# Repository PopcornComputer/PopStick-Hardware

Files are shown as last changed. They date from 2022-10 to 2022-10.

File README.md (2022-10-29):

# PopStick™ Hardware
[][cc-by-nc-sa]
[][twitter-follow]
[][sourceparts-subreddit]
<p align="center">PopStick USB Computer Device</p>

## Purchase
**PopStick™** is available for purchase in our webstore: [https://shop.popcorncomputer.com/products/popstick][webstore]

## Learn More
For a general overview, please visit the PopStick™ USB Computer website: [https://usbcomputer.com][usbcomputer]<br>
To learn how to use **PopStick™** or learn in more detail about how it works, please make sure to check out the link to the documentation below.

## Documentation
To view the documentation for **PopStick™** please visit: [https://docs.usbcomputer.com][usbcomputer-docs]

If you have done something cool with **PopStick™** or feel that something is missing from the documentation, please feel free to open an issue in the [documentation repository][documentation-repo] or submit a Pull Request in that repository. The source files for our documentation website can be found in the /docs folder in the [documentation repository][documentation-repo].

## License & Copyright
This work is licensed under a
[Creative Commons Attribution-NonCommercial-ShareAlike 4.0 International License][cc-by-nc-sa].

[][cc-by-nc-sa]

Source Parts Inc. © 2022

**PopStick™** is a trademark of Source Parts Inc.

[cc-by-nc-sa]: http://creativecommons.org/licenses/by-nc-sa/4.0/
[cc-by-nc-sa-image]: https://licensebuttons.net/l/by-nc-sa/4.0/88x31.png
[cc-by-nc-sa-shield]: https://img.shields.io/badge/License-CC%20BY--NC--SA%204.0-lightgrey.svg
[twitter-follow]: https://twitter.com/intent/follow?screen_name=sourceparts
[twitter-follow-shield]: https://img.shields.io/twitter/follow/sourceparts?style=social&logo=twitter
[sourceparts-subreddit]: https://reddit.com/r/sourceparts
[reddit-subscribers-shield]: https://img.shields.io/reddit/subreddit-subscribers/sourceparts?style=social
[usbcomputer]: https://usbcomputer.com
[usbcomputer-docs]: https://docs.usbcomputer.com
[webstore]: https://shop.popcorncomputer.com/products/popstick
[documentation-repo]: https://github.com/PopcornComputer/PopStick

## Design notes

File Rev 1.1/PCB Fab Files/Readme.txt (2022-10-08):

Board name	: Popcorn Popstick
Rev		: 1.1

Board Technology information:

No. of Layers		- FOUR(4)

Board Size 		- 45mm x 19mm

Track/Spacing		- 6mil track and 6mil spacing.

Via			- 24mil pad and 12mil drill
               
Component		- Mixed Technology

Gerber Format		- RS274-X

=================================================================

Note :

Please refer DRILL.art for stackup details.

Please confirm IPC netlist verification.

=================================================================

List of files in GERBER / arttoplotting

TOP.art		-> Gerber, Top side artwork
GND.art		-> Gerber, Inner layer2 artwork
VCC.art		-> Gerber, Inner layer3 artwork
BOT.art		-> Gerber, Bot side artwork
SMT.art		-> Gerber, Top side Solder Mask
SMB.art		-> Gerber, Bot side Solder Mask
SST.art		-> Gerber, Top side Silkscreen
SSB.art		-> Gerber, Bot side Silkscreen

List of files in DRILL/ NC Drill

nc_tools_auto.txt	-> NC drill tool bit information
Popcorn Popstick_Rev1p1-1-4.drl	-> NC Drill file in excellon format
FAB.art			-> Gerber, Drill drawing

=================================================================

Popcorn Popstick_Rev1p1_Release.pdf -> File for visual compliance

Popcorn Popstick_Rev1p1_Release.IPC -> IPC-D-356 netlist

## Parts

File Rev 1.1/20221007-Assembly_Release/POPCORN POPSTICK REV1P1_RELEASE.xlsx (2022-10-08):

CC BY-SA 4.0 Revision: 1.1
Bill Of Materials June 30,2022 17:55:15 | Page1
Item | Quantity | Reference | Part | PCB Footprint
1 | 1 | C2 | 10uF | 0603
2 | 3 | C5,C6,C7 | 2u2 | 0603
3 | 12 | C3,C8,C9,C10,C11,C13,C17,C26,C27,C28,C29,C30 | 100nF | 0603
4 | 3 | C14,C15,C16 | 22uF | 0603
5 | 2 | C20,C23 | 1uF | 0603
6 | 2 | C24,C25 | 20pF | 0603
7 | 2 | D1,D2 | MBR0540WS | SOD-323
8 | 2 | D3,D4 | LED | 0603
9 | 1 | F1 | 0467001.NRHF | 0603
10 | 3 | L1,L2,L3 | 2u2/CMP201209UD2R2MT | 0805
11 | 3 | Q1,Q2,Q3 | MMBT3904 | SOT23-3
12 | 3 | R1,R2,R15 | 11K | 0603
13 | 3 | R3,R16,R17 | 10K | 0603
14 | 3 | R4,R10,R11 | 49K9 | 0603
15 | 1 | R21 | DNP | 0603
16 | 1 | R5 | 36K | 0603
17 | 1 | R6 | 8K2 | 0603
18 | 2 | R7 | 330R | 0603
19 | 2 | R8,R9 | 2K2 | 0603
20 | 4 | R12,R13,R14,R20 | 1K | 0603
21 | 1 | R18 | 22R | 0603
22 | 1 | R19 | 0R | 0603
23 | 2 | SW1,SW2 | KEY-2PIN_0 | SW_4P_TC3061B
24 | 1 | SW3 | SW KEY_SPDT | K3-1296S-E1
25 | 1 | U1 | F1C200s | QFN88
26 | 1 | U2 | CH340E | MSOP10
27 | 1 | U3 | W25N01GVZEIG | WSON
28 | 3 | U4,U5,U6 | JW5211 | SOT23-5
29 | 1 | XTAL1 | 24M-20pF-10PPM | CRYSTAL-4P-3225-H1A
30 | 1 | X1 | USB | USB
31 | 1 | X2 | DNP | QWIIC_CONN
32 | 1 | X3 | USB-MICROB-SOCKET | USB-MICROB-SOCKET
33 | 1 | X4 | SOFNG-TF-015 | SOFNG-TF-015
34 | 1 | X5 | DNP | soic_bite

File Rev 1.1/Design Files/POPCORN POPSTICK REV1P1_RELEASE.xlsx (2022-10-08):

POPSTICK Revised: Thursday, June 30, 2022
CC BY-SA 4.0 Revision: 1.1
Bill Of Materials June 30,2022 17:55:15 | Page1
Item | Quantity | Reference | Part | PCB Footprint
______________________________________________
1 | 1 | C2 | 10uF | 603
2 | 4 | C3,C28,C29,C30 | 0.1uF | 603
3 | 3 | C5,C6,C7 | 2u2 | 603
4 | 8 | C8,C9,C10,C11,C13,C17,C26,C27 | 100nF | 603
5 | 3 | C14,C15,C16 | 22uF | 603
6 | 2 | C20,C23 | 1uF | 603
7 | 2 | C24,C25 | 20pF | 603
8 | 2 | D1,D2 | MBR0540WS | SOD-323
9 | 2 | D3,D4 | LED | 603
10 | 1 | F1 | 0467001.NRHF | 603
11 | 3 | L1,L2,L3 | 2u2/CMP201209UD2R2MT | 805
12 | 3 | Q1,Q2,Q3 | MMBT3904 | SOT23-3
13 | 3 | R1,R2,R15 | 11K | 603
14 | 3 | R3,R16,R17 | 10K | 603
15 | 5 | R4,R10,R11,R20,R21 | 49K9 | 603
16 | 1 | R5 | 36K | 603
17 | 1 | R6 | 8K2 | 603
18 | 2 | R7,R19 | 330R | 603
19 | 2 | R8,R9 | 2K2 | 603
20 | 3 | R12,R13,R14 | 1K | 603
21 | 1 | R18 | 22R | 603
22 | 2 | SW1,SW2 | KEY-2PIN_0 | SW_4P_TC3061B
23 | 1 | SW3 | SW KEY_SPDT | K3-1296S-E1
24 | 1 | U1 | F1C200s | QFN88
25 | 1 | U2 | CH340E | msop10
26 | 1 | U3 | W25N01GVZEIG | WSON
27 | 3 | U4,U5,U6 | JW5211 | SOT23-5
28 | 1 | XTAL1 | 24M-20pF-10PPM | CRYSTAL-4P-3225-H1A
29 | 1 | X1 | USB | USB
30 | 1 | X2 | DNP | QWIIC_CONN
31 | 1 | X3 | USB-MICROB-SOCKET | usb-mic-a01sb141bh2_4a
32 | 1 | X4 | SOFNG-TF-015 | SOFNG-TF-015
33 | 1 | X5 | SOIC BITE | soic_bite

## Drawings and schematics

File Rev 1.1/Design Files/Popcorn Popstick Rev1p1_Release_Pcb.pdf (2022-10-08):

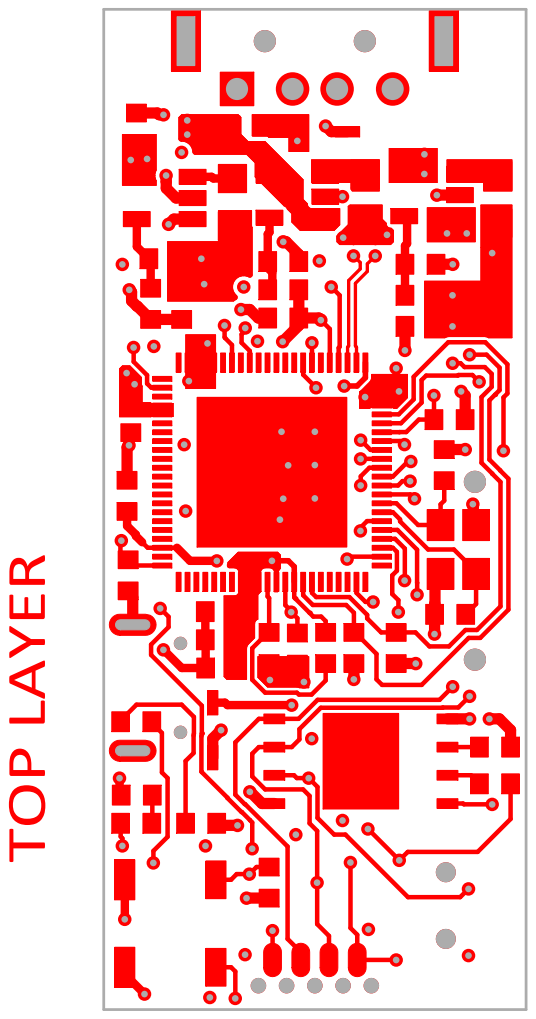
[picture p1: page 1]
TOP LAYER

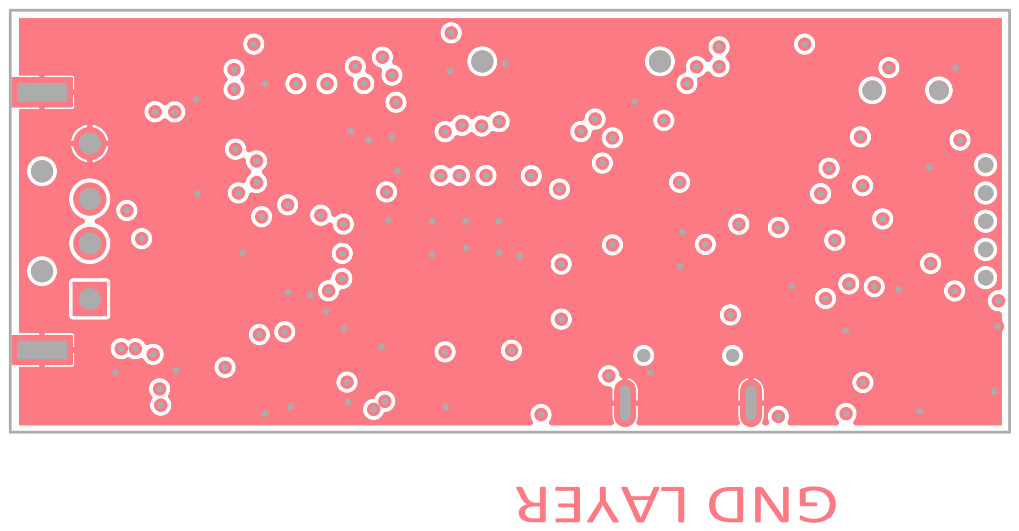
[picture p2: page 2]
GND LAYER

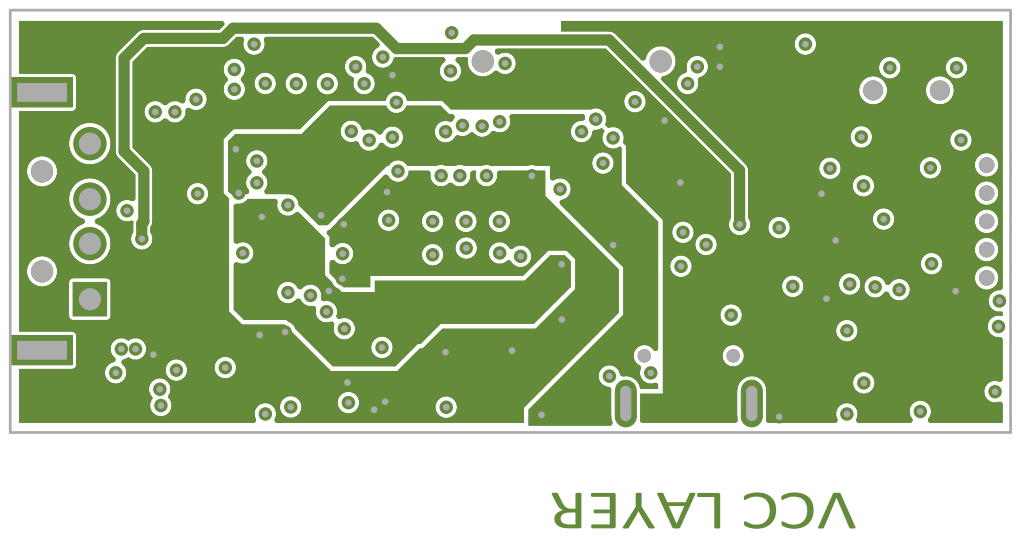
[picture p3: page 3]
VCC LAYER

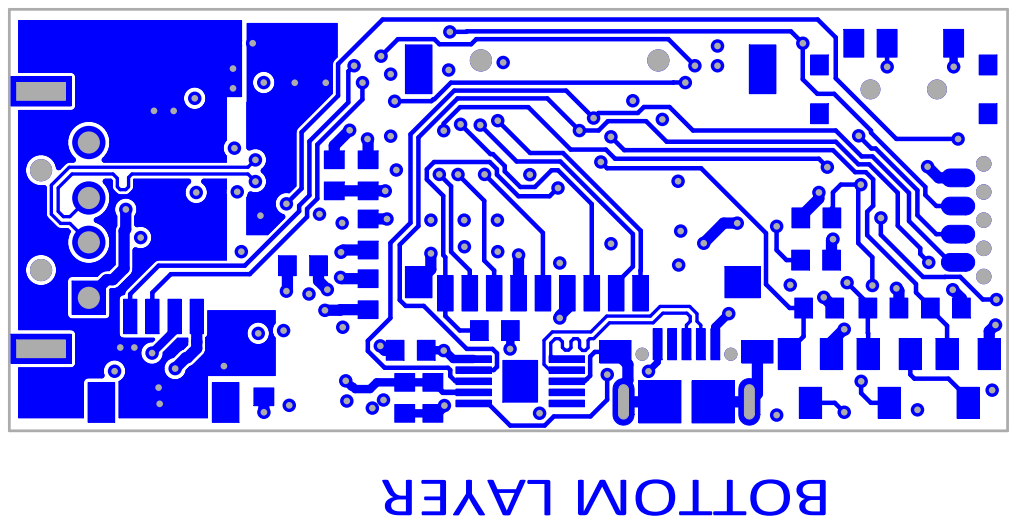
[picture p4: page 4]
BOTTOM LAYER

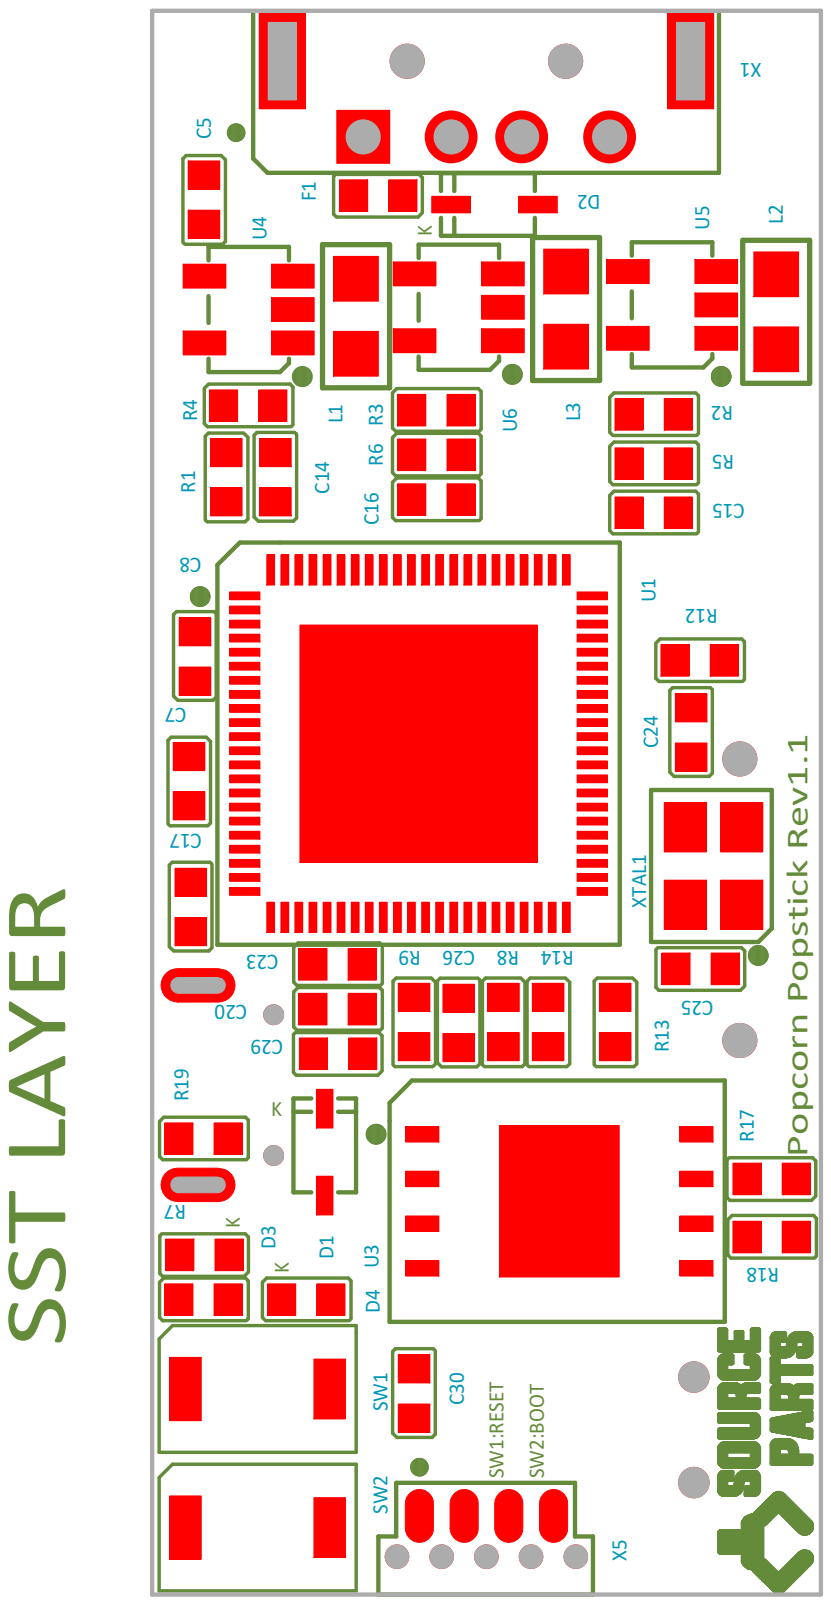
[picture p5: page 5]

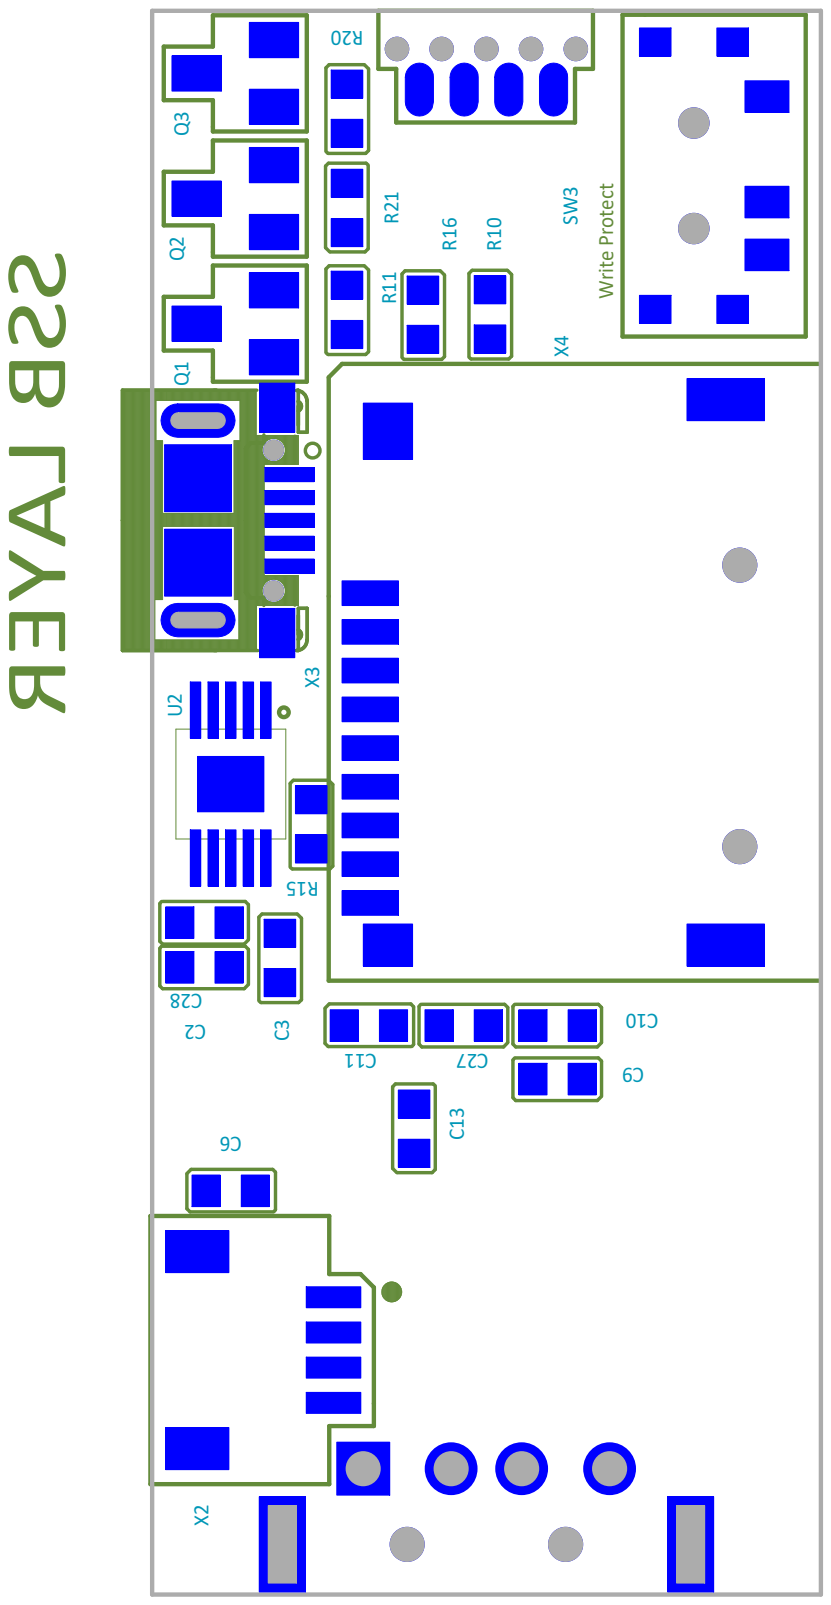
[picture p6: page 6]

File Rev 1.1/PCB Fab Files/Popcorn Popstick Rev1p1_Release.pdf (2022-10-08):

TOP LAYER

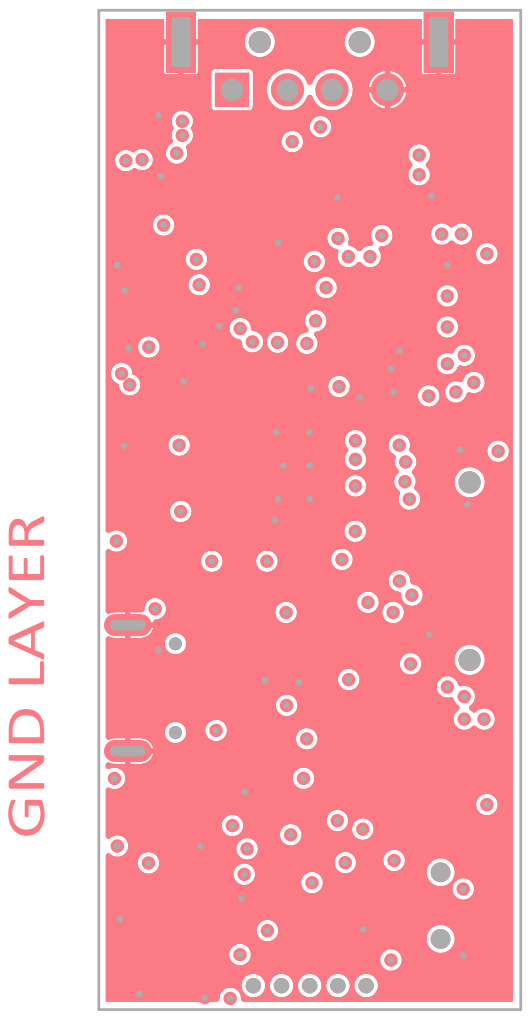
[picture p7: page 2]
GND LAYER

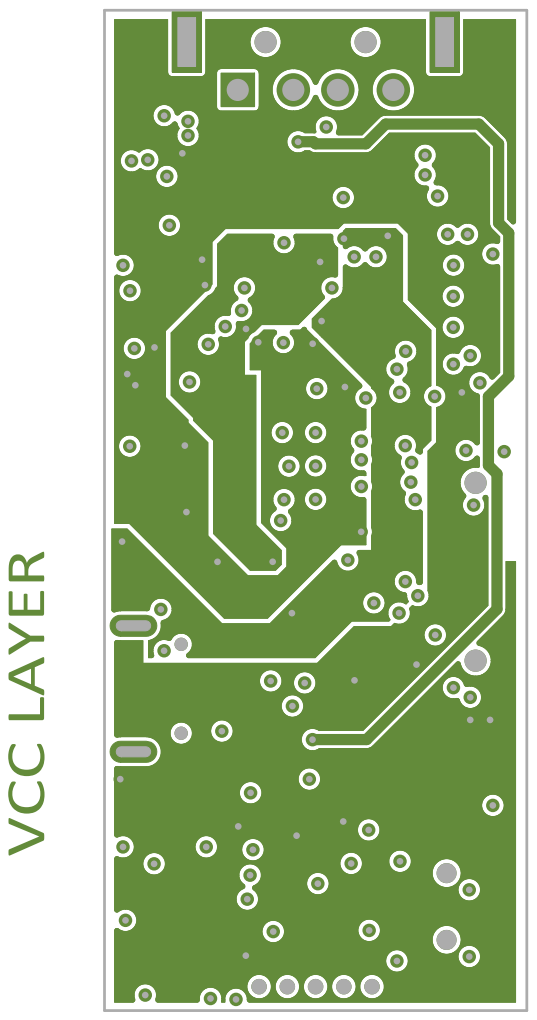
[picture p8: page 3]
VCC LAYER

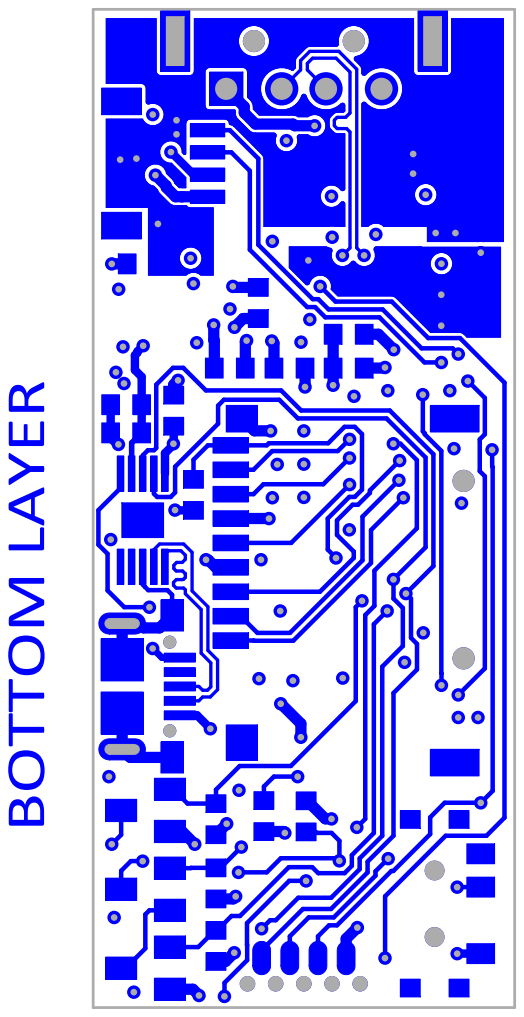
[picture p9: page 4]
BOTTOM LAYER



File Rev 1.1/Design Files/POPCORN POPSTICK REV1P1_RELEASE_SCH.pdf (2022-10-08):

# SD CARD QWIIC CONN

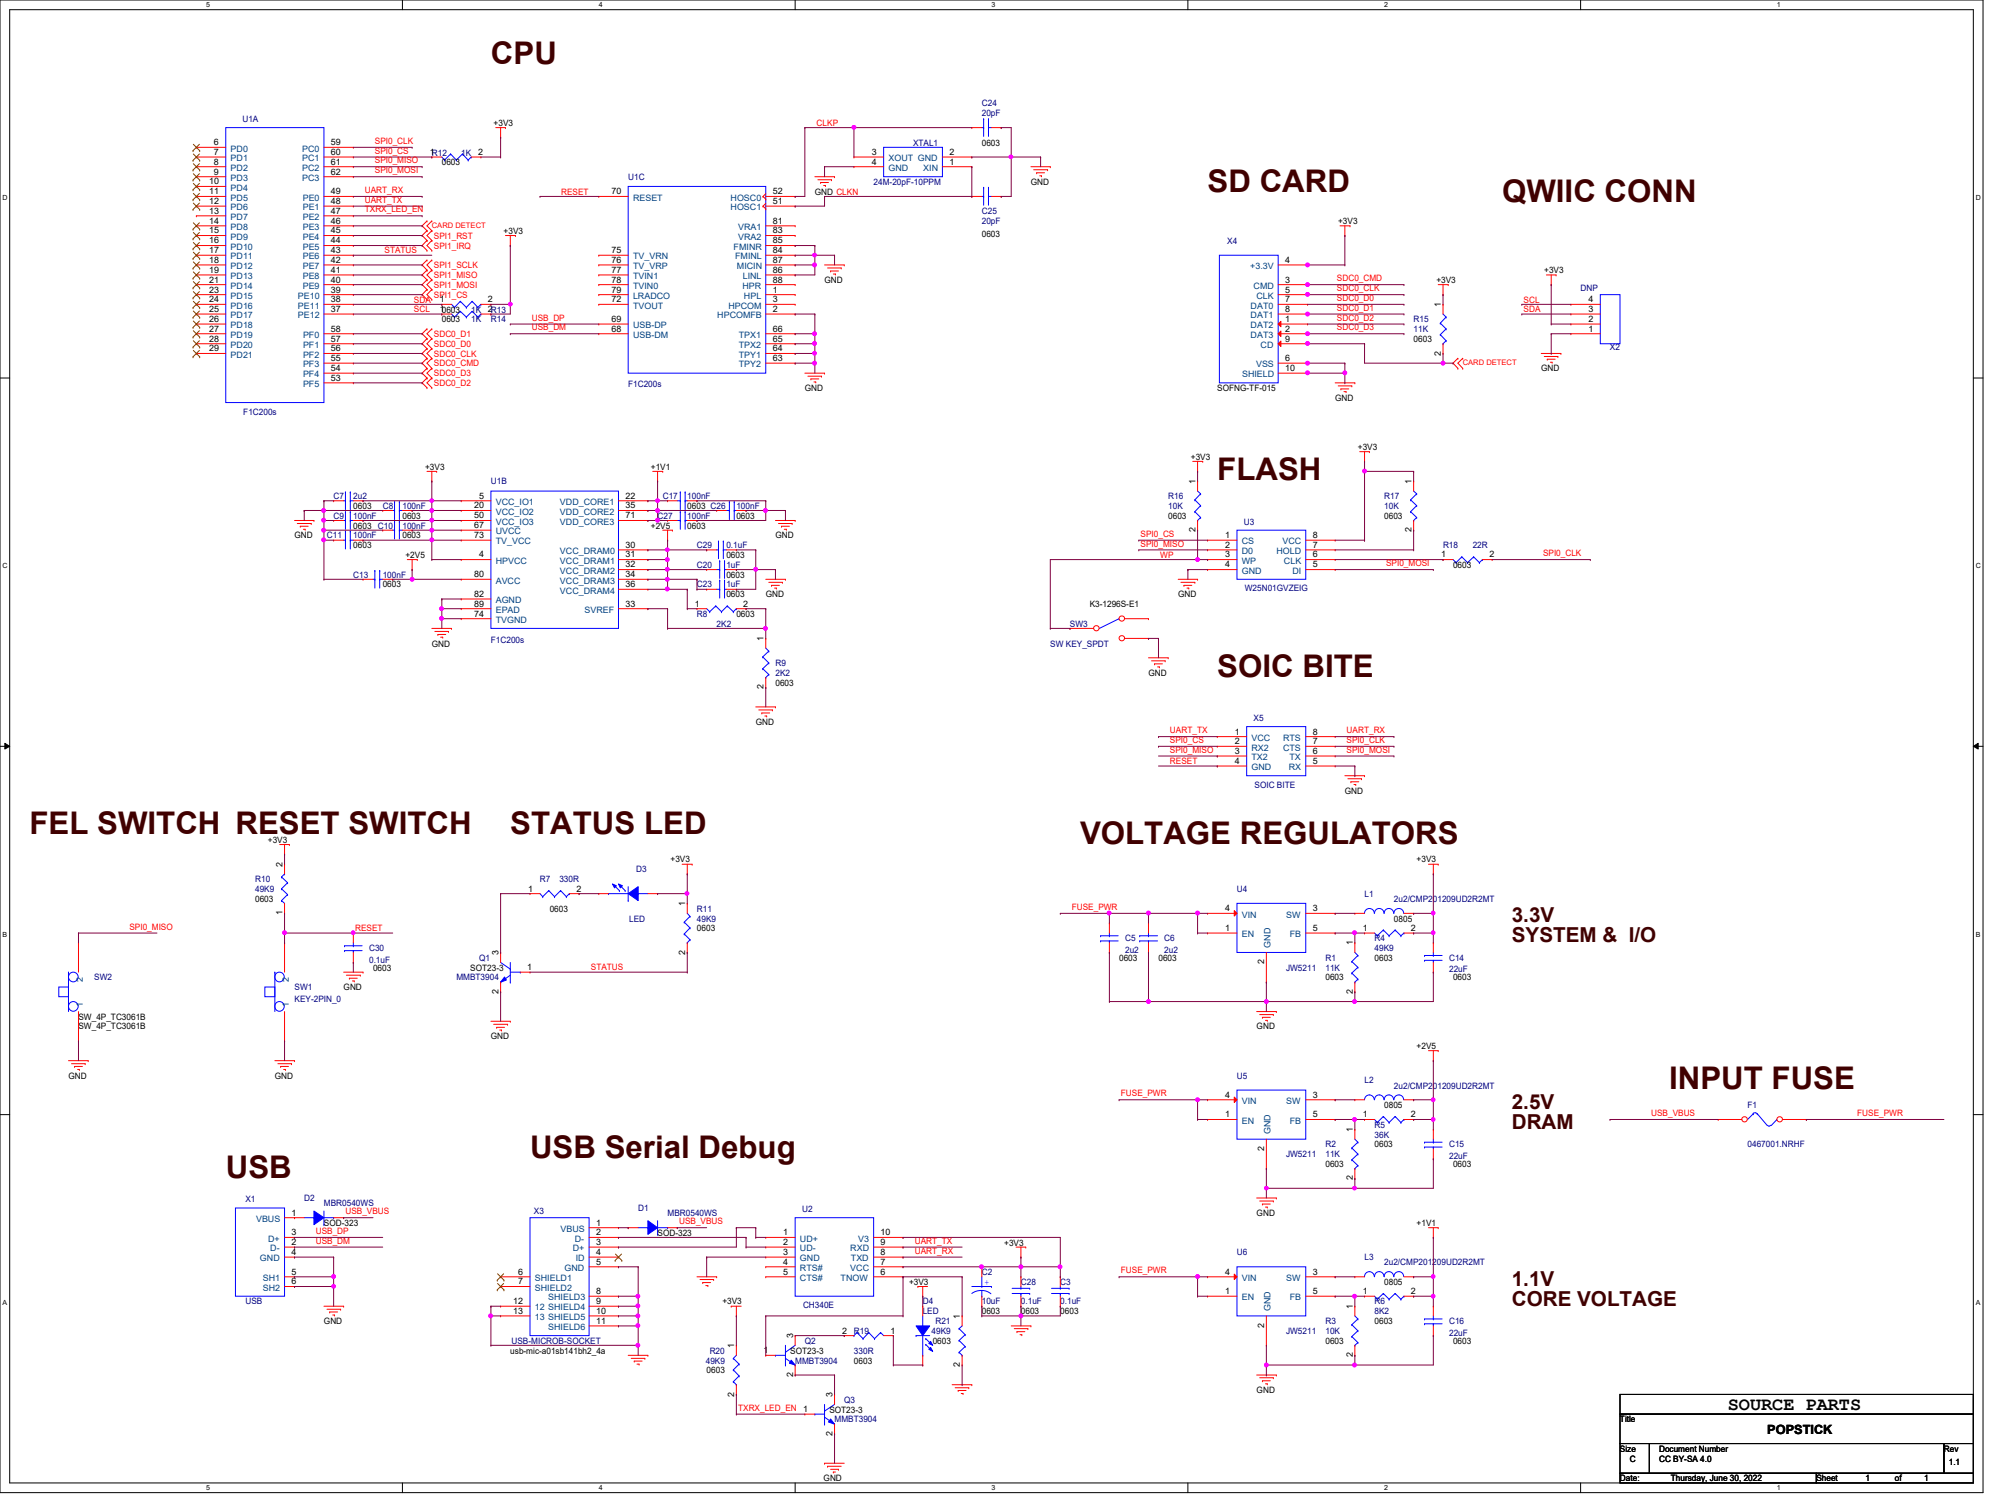
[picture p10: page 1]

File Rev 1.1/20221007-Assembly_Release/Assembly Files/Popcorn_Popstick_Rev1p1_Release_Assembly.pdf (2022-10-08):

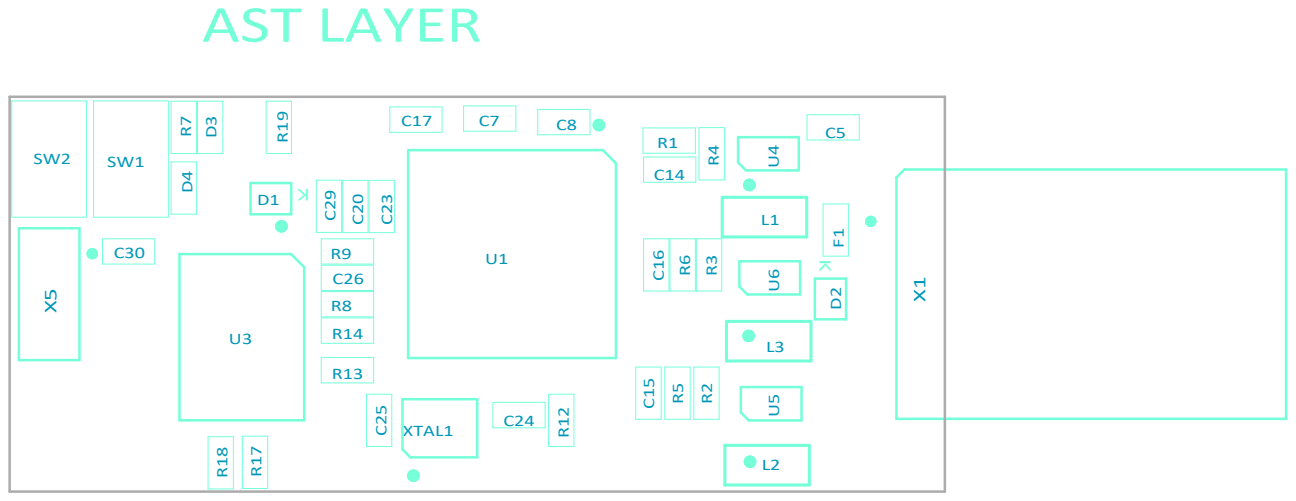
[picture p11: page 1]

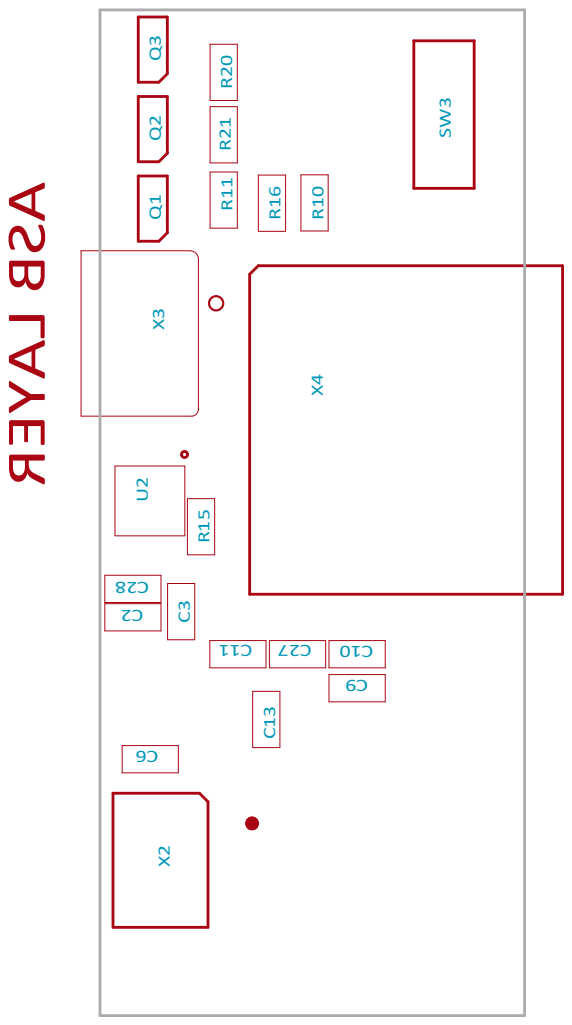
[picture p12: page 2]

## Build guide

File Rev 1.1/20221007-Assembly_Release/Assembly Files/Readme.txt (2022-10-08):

Board name	: Popcorn Popstick
Rev		: 1.1

Board Technology information:

No. of Layers		- FOUR(4)

Board Size 		- 45mm x 19mm

Track/Spacing		- 6mil track and 6mil spacing.

Via			- 24mil pad and 12mil drill
               
Component		- Mixed Technology

Gerber Format		- RS274-X

=================================================================

List of files in ASSY/ for Assembly
PMT.art		-> Gerber, Top Side Solder Paste
PMB.art		-> Gerber, Bot Side Solder Paste
ADT.art		-> Gerber, Top Assembly Drawing
ADB.art		-> Gerber, Bot Assembly Drawing
place_txt.txt	-> Component x,y Locations

=================================================================
Popcorn_Popstick_Rev1p1_Release_BOM.xlsx -> Bill Of Materials
Popcorn Popstick_Rev1p1_Assembly.pdf -> File for visual compliance

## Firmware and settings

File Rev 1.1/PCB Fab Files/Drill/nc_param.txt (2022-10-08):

INTEGER-PLACES         2
DECIMAL-PLACES         5
X-OFFSET               0.000000
Y-OFFSET               0.000000
FEEDRATE               1
COORDINATES            ABSOLUTE
OUTPUT-UNITS           METRIC
TOOL-ORDER             INCREASING
REPEAT-CODES           YES
SUPPRESS-LEAD-ZEROES   NO
SUPPRESS-TRAIL-ZEROES  NO
SUPPRESS-EQUAL         NO
TOOL-SELECT            YES
OPTIMIZE_DRILLING      NO
ENHANCED_EXCELLON      NO
HEADER                 none
LEADER                 12
CODE                   ASCII
SEPARATE               NO
SEPARATE-ROUTING       NO
DRILLING               LAYER-PAIR
BACKDRILL              NO
CAVITY                 NO
COUNTER                NO
TOLERANCE_DRILL        NO
TOLERANCE_TRAVEL       NO
TOOL_SIZE              NO
ROTATION               NO
NON_STANDARD           NO
TOTAL_DRILL            NO
SEPARATE_SLOT          NO
SUPPRESS_TOLERANCE     NO
SUPPRESS_TOOLSIZE      NO
SUPPRESS_ROTATION      NO

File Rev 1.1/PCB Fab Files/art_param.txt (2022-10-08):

DEVICE-TYPE           GERBER_RS274X
OUTPUT-UNITS          MM
FILM-SIZE             2400000 1600000
FORMAT                5.5
ABORT-ON-ERROR        YES
SCALE                 1
SUPPRESS-LEAD-ZEROES  YES
SUPPRESS-TRAIL-ZEROES NO
SUPPRESS-EQUAL        YES
UNDEF-APT-CONT        NO

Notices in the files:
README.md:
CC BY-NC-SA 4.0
